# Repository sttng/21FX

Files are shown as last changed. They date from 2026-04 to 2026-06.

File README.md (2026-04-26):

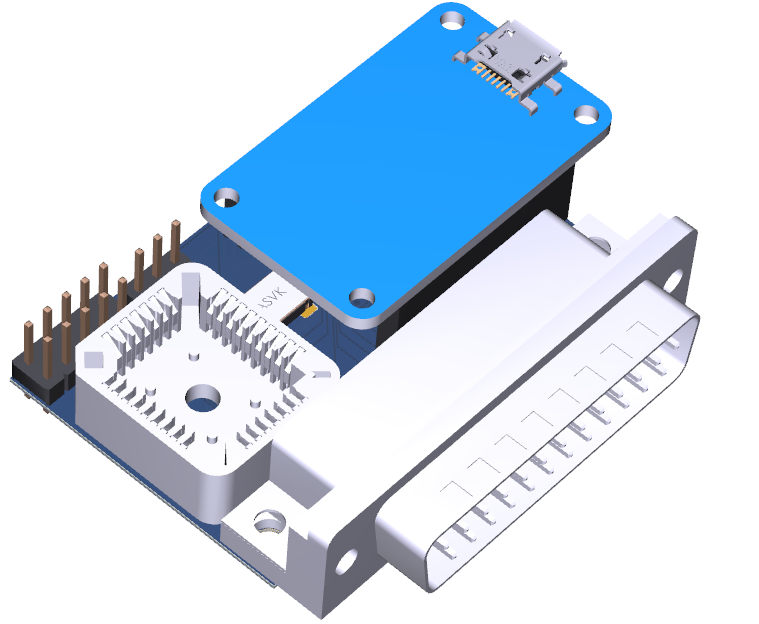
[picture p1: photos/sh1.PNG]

# 21FX - An SNES Primary Bootloader (formerly SNES-Hook) 
This project includes Altium and verilog design files for an SNES CPLD 
expansion port to perform a simple reset hijacking and present a primary 
bootloader for the SNES to use. The bootloader is intended to be used in
conjunction with byuu's Controller Port Serial Cable for uploading
executable code into WRAM.

Updates
---------------------------------------------------------------------
4/14/2016 - REV C boards back and tested working. The boards now conform
to the new SNES expansion bridge DB-25 connector. byuu has produced the IPLROM
which is programmed to the EEPROM. Couple of issues with some power off noise
to the 232H but nothing serious

21FX - Rev C (Full Release)
---------------------------------------------------------------------
In this release we have changed the entire form factor of the board.
The board now conforms to a DB-25 connector and will mate to the new
SNES expansion bridge. We have also kept the same size CPLD and decided
to keep the IPLROM on a separate microchip 5v parallel eeprom chip. Lastly
the project no longer targets byuu's USART board. It instead has the connector
footprint for the Adafruit FT232H USB transceiver board. The IPLROM targets
all back and forth communication through this device.

SNES-Hook v1.1 REV B (Full Release)
---------------------------------------------------------------------
Updated top verilog file to include 2 more force/glitch outputs for
providing extra current strength on the glitched lines.

SNES-Hook v1.0 (Full Release)
---------------------------------------------------------------------
This a preliminary full release of SNES-Hook. In the release is the 
verilog files, Altium board design files and the quartus project which 
targets the MAX7000S CPLD on the SNES-Hook board.

@defparam

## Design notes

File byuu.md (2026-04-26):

- From: https://byuu.org/projects/21fx 
- Archive.org: https://archive.is/2020.03.22-085708/https://byuu.org/projects/21fx

# 21fx
## 21fx

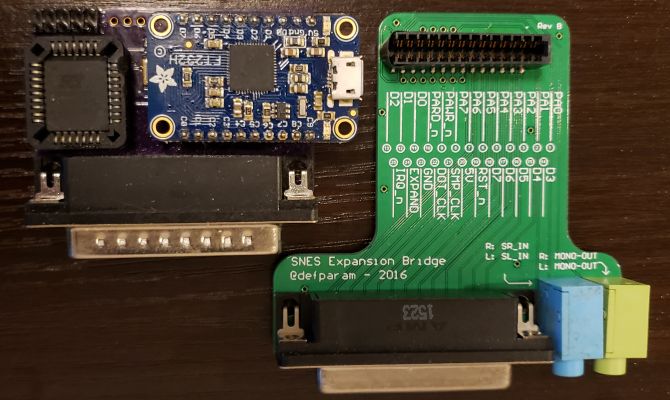
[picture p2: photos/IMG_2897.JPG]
21fx board


21fx is an expansion port device for the SNES designed for emulation research.
The hardware was designed by defparam, and the firmware and register interface was designed by byuu.
It consists of two components: an expansion bridge to connect to the SNES expansion port and convert the interface to a DB25 data port, a stereo audio input jack, and a monaural audio output jack; and a hook which contains the actual logic and interfaces between the expansion port and the SNES.
It works by monitoring the SNES address bus and overriding the SNES reset vector address to jump into a custom 124-byte boot loader. From here, an SNES program can be uploaded into memory and then executed for analyzing either the SNES console itself, or any cartridge currently connected to the SNES. Said program can communicate bidirectionally with a host PC over a USB-TTY interface at speeds of around 1 MiB per second (the IPLROM interface is designed for size constraints over speed, and can achieve a transfer rate of 175 KiB per second. A second-stage program can expand upon this with a faster transfer routine.)
Unfortunately, due to the non-standard expansion port used by the SNES, it is not possible to mass produce these devices. One would have to hand-modify an appropriate card edge connector and mount it to the PCB themselves in order to create their own from the open source hardware project files.

## Links

[GitHub Project Page](https://github.com/defparam/21FX) 
 
## IPLROM

```
//21fx IPLROM

//jump: $216678 (uint24)offset $00
//save: $216678 (uint24)offset $01 (uint16)length $00 snes->link[length]
//load: $216678 (uint24)offset $01 (uint16)length $01 link->snes[length] $00
//exec: $216678 (uint24)offset $01 (uint16)length $01 link->snes[length] $01

//NTSC clock rate: 21477272 * 1324 / 1364
//116 clocks per iteration of inner load/save loops
//maximum throughput: 179719 bytes/second

//IPLROM is re-entrant
//all registers are destroyed; HDMA and FastROM are disabled
//if link is disconnected; original reset vector will be invoked
//if link is connected; $4377-$437b is destroyed (HDMA channel 7)

//note 1: length of zero is equivalent to 65536
//note 2: offset cannot cross bank boundaries; use one transfer per bank

architecture wdc65816
base $2184

function boot {
  sei; clc; xce
  rep #$30; lda #$2100; tad
  tax; stz $0c,x
  sep #$20; ldx #$437b; txs

  handshake:
    //connected?
    lda $fe; bne +
    jmp ($fffc); +

    //signature (24-bit)
    jsr read; cmp #$21; bne handshake
    jsr read; cmp #$66; bne handshake
    jsr read; cmp #$78; bne handshake

  //offset (24-bit)
  jsr read; pha; pha; plb  //bank
  jsr read; pha; xba       //hi
  jsr read; pha; tax       //lo

  //execute?
  jsr read; beq exec

  //length (16-bit)
  jsr read; xba  //hi
  jsr read; tay  //lo

  //load?
  jsr read; beq save

  load:
    -; bit $fe; bpl -
    lda $ff; sta $0000,x
    inx; dey; bne load
    jsr read; beq boot

  exec:
    php; rti

  save:
    -; bit $fe; bvc -
    lda $0000,x; sta $ff
    inx; dey; bne save
    bra boot
}

function read {
  -; bit $fe; bpl -
  lda $ff; rts
}
```

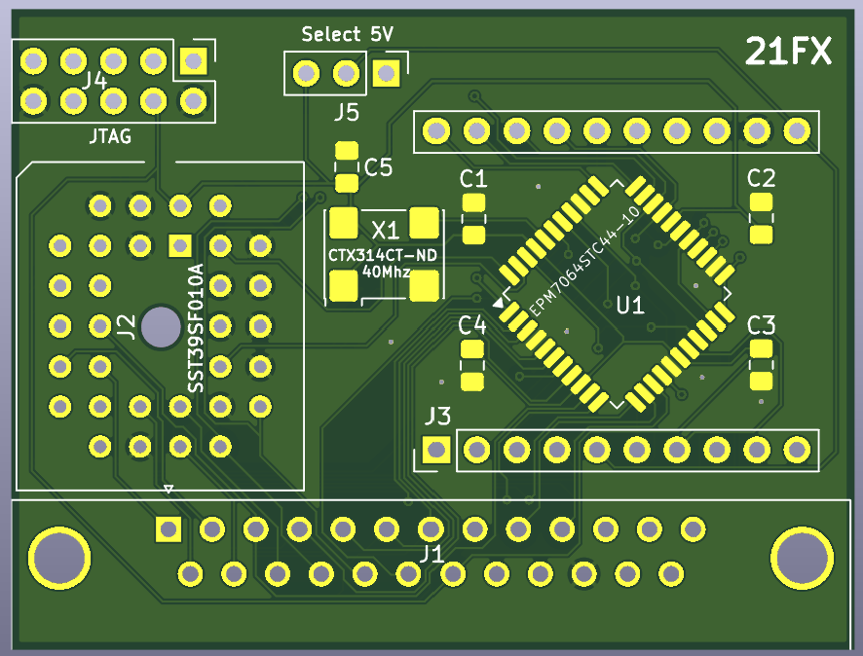
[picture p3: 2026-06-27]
KiCAD/21FX-KiCad.png

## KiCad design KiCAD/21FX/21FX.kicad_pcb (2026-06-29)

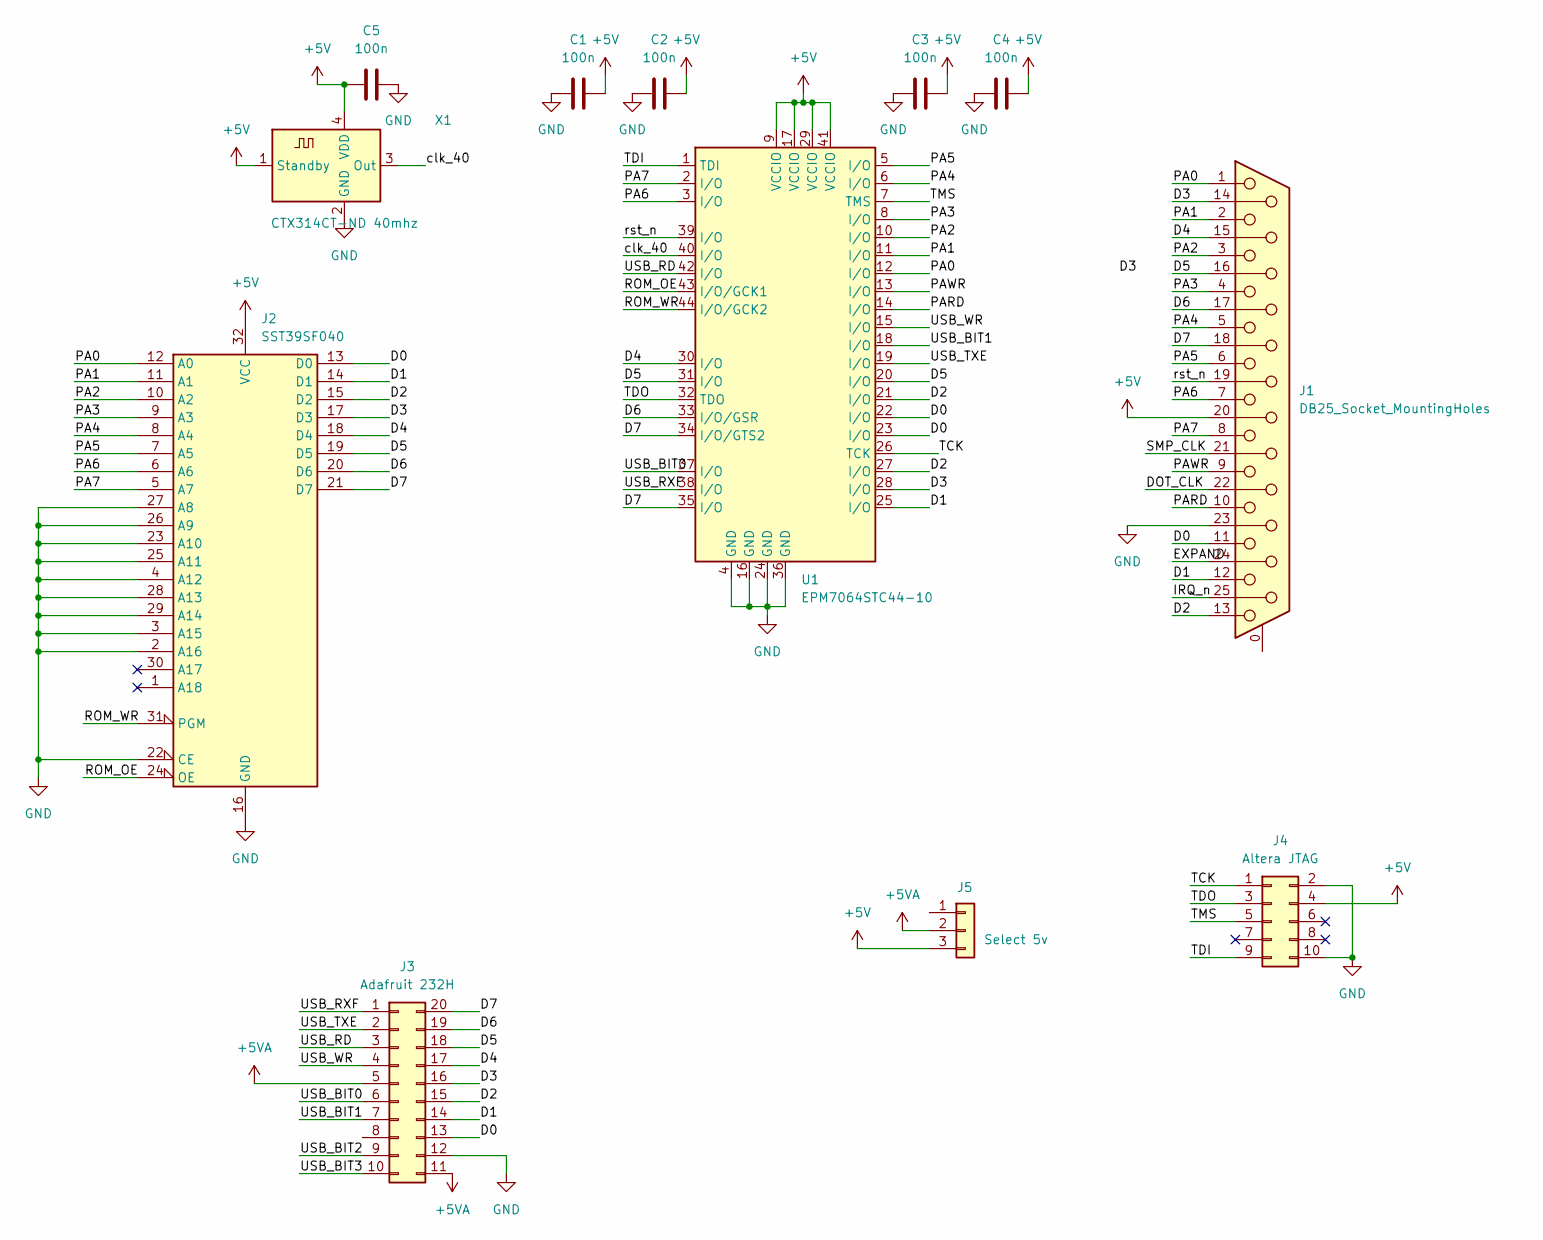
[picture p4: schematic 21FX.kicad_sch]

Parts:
C1, C2, C3, C4, C5: 100n; C_0805_2012Metric_Pad1.18x1.45mm_HandSolder
J1: DB25_Socket_MountingHoles; DSUB-25_Pins_Horizontal_P2.77x2.84mm_EdgePinOffset4.94mm_Ho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
J2: SST39SF040; PLCC-32_THT-Socket
J3: Adafruit 232H; PinHeader_2x10_P2.54mm_Vertical
J4: Altera JTAG; PinHeader_2x05_P2.54mm_Vertical
J5: Select 5v; PinHeader_1x03_P2.54mm_Vertical
U1: EPM7064STC44-10; TQFP-44_10x10mm_P0.8mm
X1: CTX314CT-ND 40mhz; Oscillator_SMD_Abracon_ASV-4Pin_7.0x5.1mm

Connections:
+5V: C1.2, C2.2, C3.2, C4.2, C5.1, J1.20, J2.32 (VCC), J4.4, J5.3, U1.9 (VCCIO), U1.17 (VCCIO), U1.29 (VCCIO), U1.41 (VCCIO), X1.1 (Standby), X1.4 (VDD)
+5VA: J3.5, J3.11, J5.2
/D0: J1.11, J2.13 (D0), J3.13, U1.22 (I/O), U1.23 (I/O)
/D1: J1.12, J2.14 (D1), J3.14, U1.25 (I/O)
/D2: J1.13, J2.15 (D2), J3.15, U1.21 (I/O), U1.27 (I/O)
/D3: J1.14, J2.17 (D3), J3.16, U1.28 (I/O)
/D4: J1.15, J2.18 (D4), J3.17, U1.30 (I/O)
/D5: J1.16, J2.19 (D5), J3.18, U1.20 (I/O), U1.31 (I/O)
/D6: J1.17, J2.20 (D6), J3.19, U1.33 (I/O/GSR)
/D7: J1.18, J2.21 (D7), J3.20, U1.34 (I/O/GTS2), U1.35 (I/O)
/DOT_CLK: J1.22
/EXPAND: J1.24
/IRQ_n: J1.25
/PA0: J1.1, J2.12 (A0), U1.12 (I/O)
/PA1: J1.2, J2.11 (A1), U1.11 (I/O)
/PA2: J1.3, J2.10 (A2), U1.10 (I/O)
/PA3: J1.4, J2.9 (A3), U1.8 (I/O)
/PA4: J1.5, J2.8 (A4), U1.6 (I/O)
/PA5: J1.6, J2.7 (A5), U1.5 (I/O)
/PA6: J1.7, J2.6 (A6), U1.3 (I/O)
/PA7: J1.8, J2.5 (A7), U1.2 (I/O)
/PARD: J1.10, U1.14 (I/O)
/PAWR: J1.9, U1.13 (I/O)
/ROM_OE: J2.24 (OE), U1.43 (I/O/GCK1)
/ROM_WR: J2.31 (PGM), U1.44 (I/O/GCK2)
/SMP_CLK: J1.21
/TCK: J4.1, U1.26 (TCK)
/TDI: J4.9, U1.1 (TDI)
/TDO: J4.3, U1.32 (TDO)
/TMS: J4.5, U1.7 (TMS)
/USB_BIT0: J3.6, U1.37 (I/O)
/USB_BIT1: J3.7, U1.18 (I/O)
/USB_BIT2: J3.9
/USB_BIT3: J3.10
/USB_RD: J3.3, U1.42 (I/O)
/USB_RXF: J3.1, U1.38 (I/O)
/USB_TXE: J3.2, U1.19 (I/O)
/USB_WR: J3.4, U1.15 (I/O)
/clk_40: U1.40 (I/O), X1.3 (Out)
/rst_n: J1.19, U1.39 (I/O)
GND: C1.1, C2.1, C3.1, C4.1, C5.2, J1.23, J2.2 (A16), J2.3 (A15), J2.4 (A12), J2.16 (GND), J2.22 (CE), J2.23 (A10), J2.25 (A11), J2.26 (A9), J2.27 (A8), J2.28 (A13), J2.29 (A14), J3.12, J4.2, J4.10, U1.4 (GND), U1.16 (GND), U1.24 (GND), U1.36 (GND), X1.2 (GND)

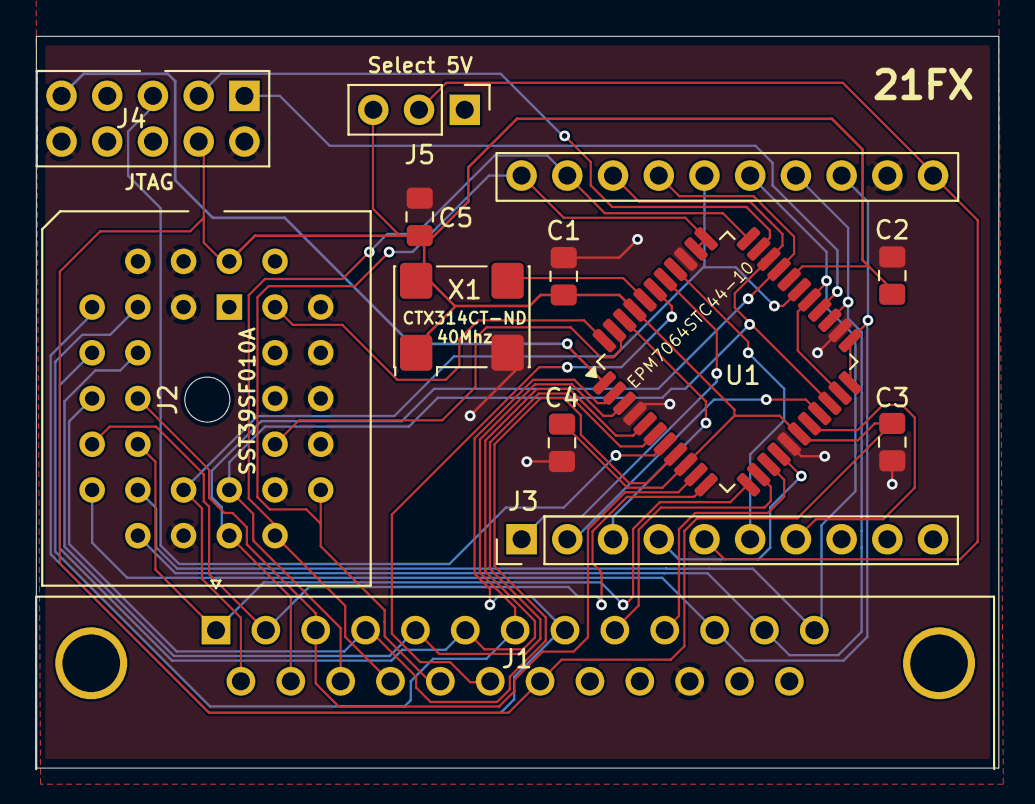
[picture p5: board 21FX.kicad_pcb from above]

Board: 4 copper layers, 53.5 x 40.6 mm, 12 parts (0 on the bottom side), 35 nets.
